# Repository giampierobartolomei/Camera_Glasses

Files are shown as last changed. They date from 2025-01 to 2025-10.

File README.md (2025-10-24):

# Camera_Glasses • Wearable camera system for synchronized multimodal data collection and research applications (adaption from ESP32-CAM_MJPEG2SD repo)

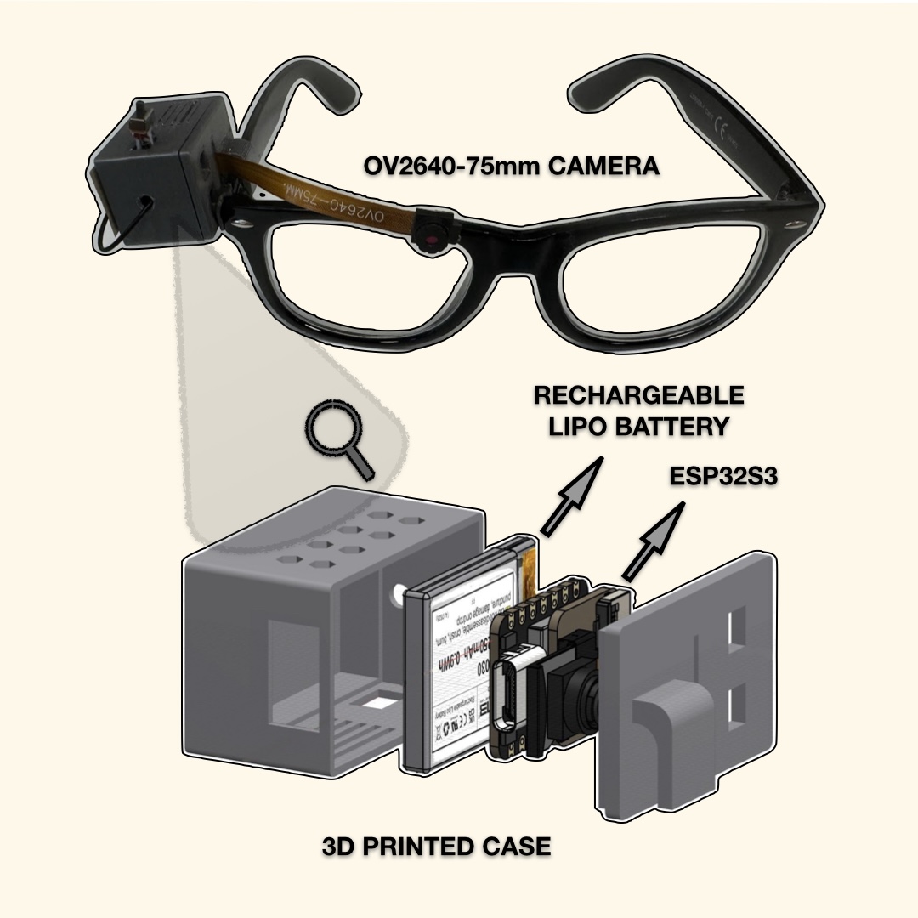
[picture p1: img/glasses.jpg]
Camera Glasses Overview


---

## Overview
The **Camera_Glasses** project provides a compact, wearable vision system based on the ESP32 microcontroller for synchronized multimodal data acquisition.  
The device records and streams video, interfaces via **Bluetooth** with the **ECHO** and **IM‑TWIN** Android applications, and integrates seamlessly with the **Platform Application** for synchronized analysis.

---

## Bill of Materials
| Component | Description | Link |
|---|---|---|
| LP502030 3.7 V 250 mAh Li‑ion Polymer Battery | Rechargeable | [Amazon](https://amzn.eu/d/fRJ3vzB) |
| 3D Printed Case | STL provided in repo | GitHub |
| OV2640 2 MP 20 cm Camera Module (66° FOV) | Main sensor | [AliExpress](https://www.aliexpress.com) |
| Xiao ESP32 Module | Main controller | [AliExpress](https://www.aliexpress.com) |
| Misc. | Wires, switch, solder, 3M bioadhesive tape, super glue | — |

---

## Hardware Assembly

### Components Overview
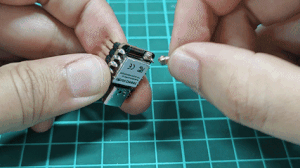
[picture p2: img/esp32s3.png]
Assembly Diagram


Follow the steps to assemble the prototype:

1. **3D print** the case (STL files provided in the repository).  
2. **Install** the antenna, expansion board, and 200 mm OV2640 camera.  
3. **Insert** a FAT32‑formatted microSD card.  
4. **Connect** the battery, switch, and camera module as shown below.  
5. **Assemble** and close the case, ensuring that the camera cable passes through the slot without bending.

### Battery and Switch Preparation
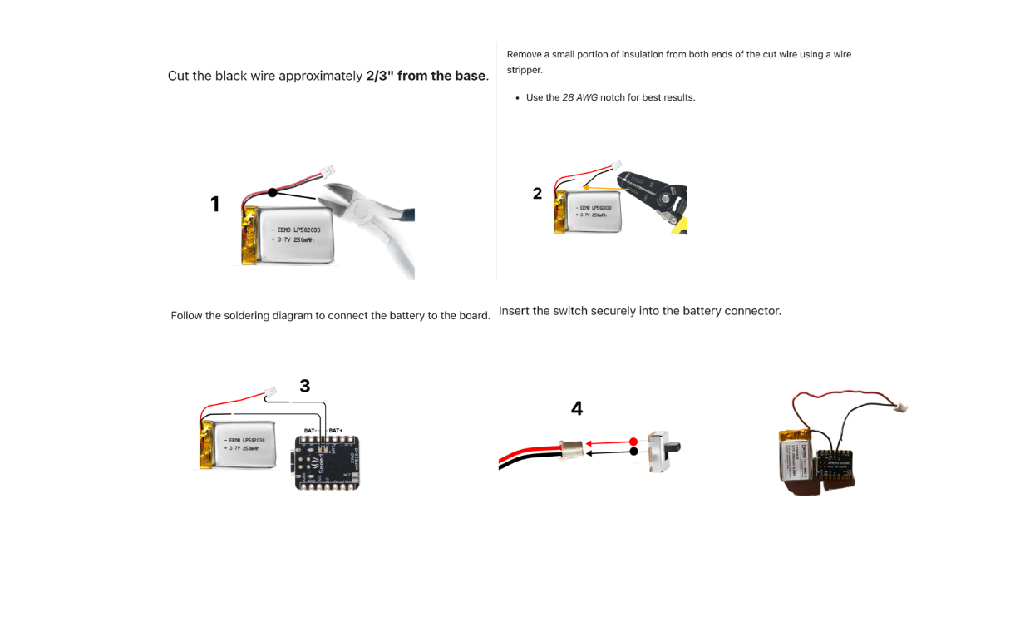
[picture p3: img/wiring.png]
Battery Wiring Steps


Ensure proper soldering of the switch and battery following the indicated diagram.

---

## Firmware Installation

1. Clone the repository:  
   ```bash
   git clone https://github.com/giampierobartolomei/Camera_Glasses.git
   ```
2. Copy the `data` folder (`CameraGlass/ESP32‑CAM_MJPEG2SD/data`) to the microSD card.  
3. Open the `.ino` file in Arduino IDE and check these settings:  
   - **Espressif Core:** 3.1.1  
   - **PSRAM:** Enabled (`Tools > PSRAM > OPI_PSRAM`)  
   - **Partition Scheme:** 3 MB APP  
4. If the upload fails, press and hold the **Boot** button while connecting the USB cable, then release it once uploading starts.

---

## First Use

The device now operates **via Bluetooth** only (Wi‑Fi mode deprecated).  
Default settings are pre‑loaded: **SVGA (800×600), 20 fps, motion detect disabled**.

### Recording Control Options

#### 1. Using Smartphone (nRF Connect)
- Connect to **CameraModule** via Bluetooth.  
- Send the UTF‑8 string commands:  
  - `rec` → start recording  
  - `stp` → stop recording  

#### 2. Using ECHO or IM‑TWIN Android App
- Connect the **TWC device** and tap the **Camera** button.  
- Once connected, the button turns **green**.  
- Tap **Rec** to start/stop recording.  
- The orange LED on the glasses blinks during active recording.

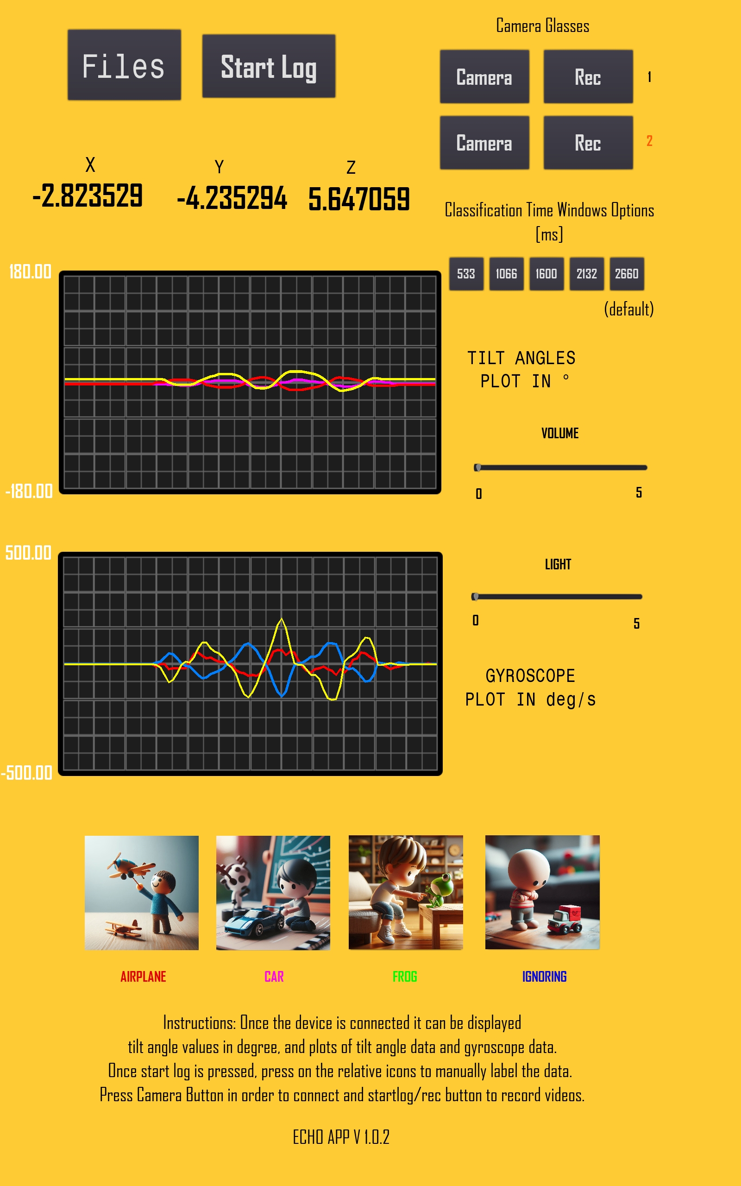
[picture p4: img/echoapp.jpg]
ECHO App Interface


---

## Computer Vision Integration

To process recorded videos with the **Computer Vision repository**:

1. Record video and save it to the microSD card.  
2. Copy `.avi` file to the computer and convert to `.mp4`:  
   ```bash
   ffmpeg -i input.avi -c:v libx264 -crf 23 -preset medium -c:a aac -b:a 128k output.mp4
   ```
3. If rotation is needed:  
   ```bash
   ffmpeg -i output.mp4 -vf "transpose=2" -c:a copy output_r.mp4
   ```

To synchronize with ECHO logs:
1. Save ECHO log as `.csv`.  
2. Process using `downsampling.py` and `plotanimation.py` (available in the **Echo repository**).  
3. Compare results using **Platform Application** for unified visualization.

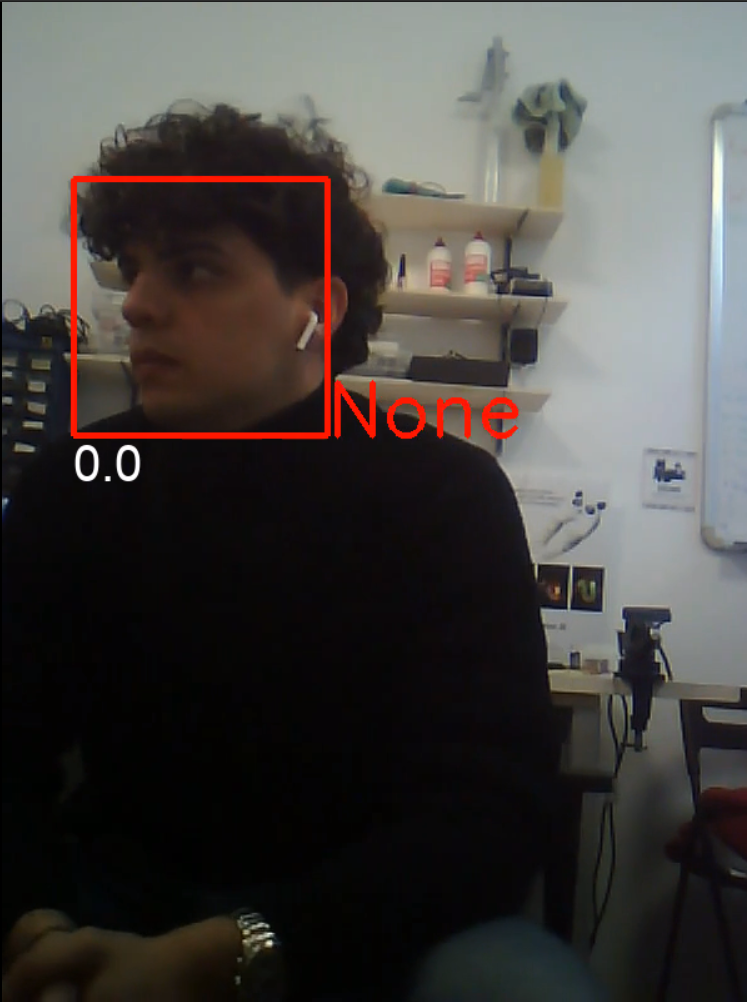
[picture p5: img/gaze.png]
Gaze Analysis Example


---

## Charging and Power Monitoring

- Connect a **USB‑C cable** while the device is ON.  
- The red LED inside the port blinks during charging and turns off when complete.  
- The orange LED indicates device power.  
- For battery voltage reading, use a 100 kΩ + 100 kΩ voltage divider (D4 → GND / Battery +).

---

## Platform Integration

1. Mount **Camera Glasses** and **ECHO**.  
2. Flash firmware and install the **ECHO App**.  
3. Turn on both devices (red LED for ECHO, orange LED for glasses).  
4. Connect via the app; both camera buttons should turn green when ready.  
5. Press **Start LOG** to begin synchronized recording.  
6. For new sessions, restart the app to ensure correct timestamps.  
7. Save logs and videos, convert with FFmpeg, and load into the **Platform Application** for analysis.

Platform GUI

---

## Repository Layout
```
Camera_Glasses/
├─ firmware/                # Arduino firmware (.ino)
├─ data/                    # Web UI / static assets
├─ 3d_models/               # STL case and lens holder
├─ docs/                    # images, diagrams
└─ README.md
```

---

## License
Code released under the **MIT License**.  
Images and documentation under **CC BY 4.0**.

---

## Citation
If you use Camera_Glasses in academic work, please cite this repository and the related Echo and Platform publications.

---

Exploded View

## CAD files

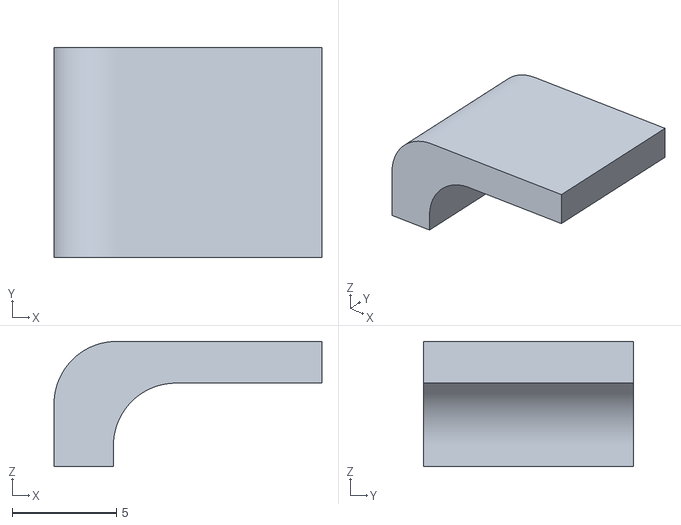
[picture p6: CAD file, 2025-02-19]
stl case files/gancio.stl
12.8 x 10.1 x 6.00

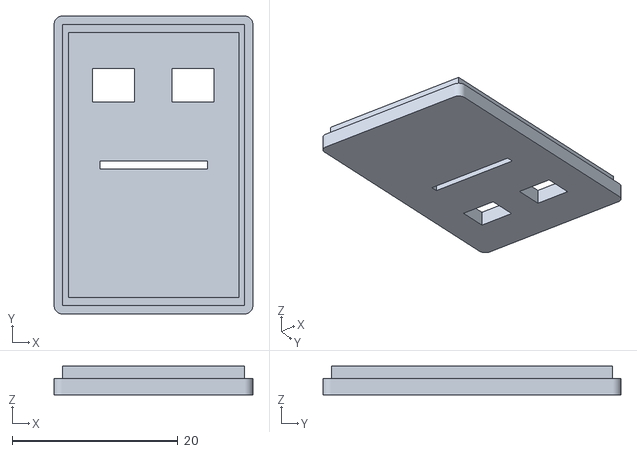
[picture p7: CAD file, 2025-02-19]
stl case files/tappo.stl
24.0 x 36.0 x 3.50

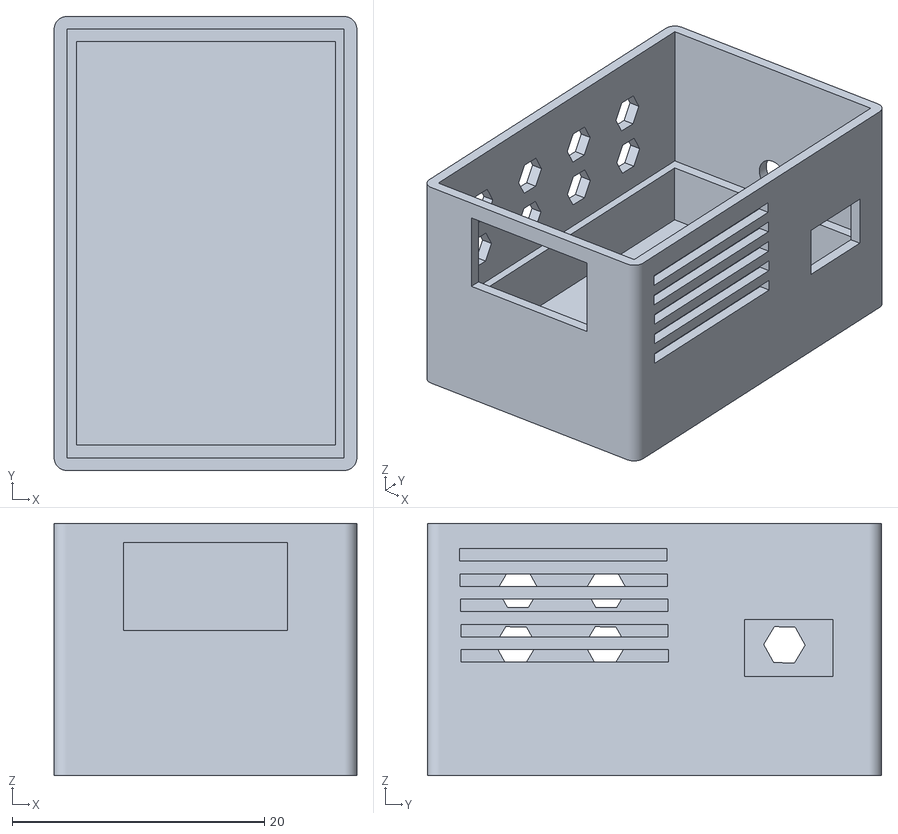
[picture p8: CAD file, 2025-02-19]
stl case files/base.stl
24.0 x 36.0 x 20.0

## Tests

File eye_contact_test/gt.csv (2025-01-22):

gt
0
0
0
0
0
0
0
0
0
0
0
0
0
0
0
0
0
0
0
0
0
0
0
1
1
1
1
1
1
1
1
1
1
1
1
1
1
1
1
0
0
0
0
0
1
1
1
1
1
1
1
1
1
1
0
0
0
0
0
0
0
1
1
1
1
1
1
1
1
1
1
1
0
0
0
0
0
0
0
0
0
0
0
0
1
1
1
1
1
1
1
1
1
1
0
1
1
1
1
1
1
1
1
1
1
1
1
1
1
1
1
1
1
1
1
1
1
1
1
1
1
1
1
1
0
0
0
0
0
0
1
1
1
1
1
1
1
1
1
1
1
1
1
1
1
1
1
1
1
1
1
1
1
1
1
1
1
1
0
0
0
0
0
0
0
0
0
0
0
0
0
0
0
0
0
0
0
0
0
0
0
0
0
0
0
0
0
0
1
1
1
1
1
1
1
1
1
0
0
0
0
0
0
0
0
0
0
0
0
0
0
0
0
0
0
0
0
0
0
0
0
0
0
0
0
0
0
0
1
1
1
1
1
1
1
1
1
1
1
1
1
1
1
1
1
1
1
1
1
1
1
1
1
1
1
1
1
1
1
1
1
1
1
1
1
1
1
1
1
1
1
1
1
1
1
1
0
0
0
0
1
1
1
1
1
1
1
1
1
1
1
1
1
1
1
1
1
1
1
1
1
1
1
0
0
0
0
0
1
1
1
1
1
1
1
1
1
1
1
1
1
1
1
1
0
0
0
0
0
0
0
0
0
0
0
0
0
0
0
1
1
1
1
1
1
1
1
0
1
1
1
1
1
1
1
1
1
1
1
1
1
1
1
1
1
1
1
1
0
0
0
1
1
1
1
1
0
0
0
0
0
0
0
0
0
0
0
0
0
0
0
0
0
0
0
0
0
0
0
0
0
0
0
0
0
0
0
0
0
0
0
0
0
0
0
0
0
0
0
0
0
0
0
0
0
0
0
0
0
0
0
0
0
0
0
0
0
0
0
0
0
0
0
0
0
0
0
0
0
0
0
0
0
0
0
0
0
0
0
0
0
0
0
0
0
0
0
0
0
0
0
0
0
0
0
0
0
0
0
0
0
0
0
1
1
1
1
1
1
1
1
1
1
1
0
0
0
0
0
0
0
0
0
0
0
0
0
0
0
0
0
0
0
0
0
0
0
0
0
0
0
0
0
0
0
0
0
0
0
0
0
0
0
0
0
0
0
0
0
0
0
0
0
0
0
0
0
0
0
0
0
0
0
0
0
0
0
0
0
0
0
0
0
0
0
0
0
0
0
0
0
0
0
0
0
0
0
0
0
0
0
0
0
0
0
0
0
0
0
0
0
0
0
0
0
0
0
0
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

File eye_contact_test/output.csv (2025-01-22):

output
0
0
0
0
0
0
0
0
0
0
0
0
0
0
0
0
0
0
0
0
0
0
0
0
0
0
0
0
0
0
0
0
0
0
0
0
0
0
0
0
0
0
0
1
1
1
1
1
0
0
1
1
1
1
0
0
0
0
0
0
0
0
1
1
1
1
1
1
1
1
1
1
0
0
1
0
0
0
0
0
1
0
0
0
1
1
1
1
1
1
1
1
1
1
0
0
1
1
1
1
1
1
1
1
1
1
1
1
1
1
1
1
1
1
1
1
1
1
1
1
1
1
1
1
0
0
0
0
1
1
1
1
1
1
1
1
1
1
1
1
1
1
1
1
1
1
1
1
1
1
1
1
1
1
1
1
1
1
0
0
1
0
0
0
0
0
0
0
0
0
0
0
0
0
0
0
0
0
0
0
0
1
0
0
0
0
0
0
1
1
1
1
1
1
1
1
0
0
0
0
0
0
0
0
0
0
0
0
0
0
0
0
0
0
0
0
0
0
0
0
0
0
0
0
0
0
0
0
1
1
1
1
1
1
1
1
1
1
1
1
1
1
1
1
1
1
1
1
1
1
1
1
1
1
1
1
1
1
1
1
1
1
1
1
1
1
1
1
1
1
1
1
1
1
1
1
0
0
0
0
1
1
1
1
1
1
1
1
1
1
1
1
1
1
1
1
1
1
1
1
1
1
1
1
0
0
0
1
1
1
1
1
1
1
1
1
1
1
1
1
1
1
1
1
1
1
0
0
0
0
0
0
0
0
0
0
0
0
1
1
1
1
1
1
1
1
1
0
0
1
1
1
1
1
1
1
1
1
1
1
1
1
1
1
1
1
1
1
0
0
0
1
1
1
1
0
0
0
0
0
0
0
0
0
0
0
0
0
0
0
0
0
0
0
0
0
0
0
0
0
0
0
0
0
0
0
0
0
0
0
0
0
0
1
0
0
0
0
0
1
0
1
1
0
0
1
1
1
1
1
1
1
0
0
1
0
0
0
1
0
0
0
0
0
0
0
0
0
0
0
0
0
0
0
0
0
0
0
0
0
0
0
0
0
0
0
0
0
0
0
0
0
0
0
0
0
0
0
0
0
0
0
0
1
1
1
1
1
1
1
1
1
1
1
0
0
0
0
0
0
0
0
0
0
0
0
0
0
0
0
0
0
0
0
0
0
0
0
0
0
0
1
0
0
0
0
0
0
0
0
0
0
0
0
0
0
0
0
0
0
0
0
0
0
0
0
0
1
0
1
0
0
0
0
0
0
0
0
0
1
0
0
0
0
0
0
0
0
1
0
0
0
0
0
0
0
0
0
0
0
0
0
0
0
0
0
0
0
0
0
0
0
0
0
0
0
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

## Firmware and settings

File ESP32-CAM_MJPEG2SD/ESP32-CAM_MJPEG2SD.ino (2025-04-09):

/*
* Capture ESP32 Cam JPEG images into a AVI file and store on SD
* AVI files stored on the SD card can also be selected and streamed to a browser as MJPEG.
*
* s60sc 2020 - 2024

8/02: I tried to add prints on serial for battery voltage status, by modifyng this code, appGlobals.h, globals.h, pheriperals.cpp
Then I try to add WebDav functionalities. I modified also utils.cpp by putting to false use ping and setting ap ip and name.
12/02: I defined as const useMotion and commented all others declarations - it works, no more autorecording
17/02: Now battery voltage is sent on command char every ten seconds (uncomment the serial prints to read in serial monitor) in file BluetoothCamerServer.cpp. try using nRF connect iPhone app (UTF-8)
18/02: i changed max_adc values since it can change with device changing, you can see the comment in bt lib .cpp. i added also a factor for correcting R tollerance.I also modified mjpeg2sd in order to blink orange LED during recording as a DEBUG of the recording status.
24/02: ADDED AUDIO RECORDING!!!! modified appglobals appspecific & audio.cpp in order to force audio recording (by surpassing app settings) video file will contain '_S' on the end of filename. micGain is now 5 but can be higher. 
*/

#include "appGlobals.h"
//#include "SerialCommandHandler.h" //added by me
#include "BluetoothCameraServer.h" //Added by me, from max code

bool forceRecord = false; // added by me and commented the declaratiion in mjpeg2sd.cpp
//bool useMotion  == false; // whether to use camera for motion detection (with motionDetect.cpp), added by me, but only with changs on motionDetect.cpp it works
const bool useMotion = false; // Variabile costante, non modificabile

void setup() {
  logSetup();
  LOG_INF("Selected board %s", CAM_BOARD);
  // Legge e stampa subito la tensione della batteria
  float voltage = readVoltage();
  LOG_INF("Initial battery voltage: %.2fV", voltage);
  // prep storage
  if (startStorage()) {
    // Load saved user configuration
    if (loadConfig()) {
#ifndef AUXILIARY
      // initialise camera
      if (psramFound()) {
        if (ESP.getPsramSize() > 3 * ONEMEG) prepCam();
        else snprintf(startupFailure, SF_LEN, STARTUP_FAIL "Insufficient PSRAM for app: %s", fmtSize(ESP.getPsramSize()));
      } else snprintf(startupFailure, SF_LEN, STARTUP_FAIL "Need PSRAM to be enabled");
#else
      LOG_INF("AUXILIARY mode without camera");
#endif
    }
  }
  
#ifdef DEV_ONLY
  devSetup();
#endif

  // connect wifi or start config AP if router details not available
//  startWifi();

//  startWebServer();
  if (strlen(startupFailure)) LOG_WRN("%s", startupFailure);
  else {
    // start rest of services
#ifndef AUXILIARY
    startSustainTasks(); 
#endif
#if INCLUDE_SMTP
    prepSMTP(); 
#endif
#if INCLUDE_FTP_HFS
    prepUpload();
#endif
#if INCLUDE_UART
    prepUart();
#endif
#if INCLUDE_PERIPH
    prepPeripherals();
  #if INCLUDE_MCPWM 
    prepMotors();
  #endif
#endif
#if INCLUDE_AUDIO
    prepAudio(); 
#endif
#if INCLUDE_TGRAM
    prepTelegram();
#endif
#ifndef AUXILIARY
    prepRecording(); 
#endif
#if INCLUDE_I2C
  prepI2C();
  #if INCLUDE_TELEM
    prepTelemetry();
  #endif
#endif
#if INCLUDE_PERIPH
    startHeartbeat();
#endif
#if INCLUDE_RTSP
    prepRTSP();
#endif
    checkMemory("Setup");
    if (DEBUG_MEM) runTaskStats();
  } 
  
  setup_BLE_ESP32(); //from max code
  //startSerialCommandTask(forceRecord); //added by me for serial input start/stop recording and video saving
}
//It should appear: first battery level voltage(commented), pheripherals setup, total tasks and then the updating of the battery level every interval setted in bt library file .cpp (commented)
void loop() {
  // confirm not blocked in setup
  //float voltage = (float)(smoothAnalog(5)) * 3.3 * 2 / 8191;
  //LOG_INF("Initial battery voltage: %.2fV", voltage);
  LOG_INF("=============== Total tasks: %u ===============\n", uxTaskGetNumberOfTasks() - 1);
  vTaskDelete(NULL); // free 8k ram
}

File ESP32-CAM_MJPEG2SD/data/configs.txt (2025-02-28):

AP_Pass~~0~T~AP Password
AP_SSID~ESP-CAM_MJPEG_C025130CDADC~0~T~AP SSID name
AP_gw~~0~T~AP gateway
AP_ip~~0~T~AP IP Address if not 192.168.4.1
AP_sn~~0~T~AP subnet
AtakePhotos~Start~5~A~Start photogrammetry
AudActive~0~3~C~Show audio configuration
Auth_Name~~99~~na
AuxIP~~3~T~Send RC / Servo / PG commands to auxiliary IP
BabortPhotos~Abort~5~A~Abort photogrammetry
I2Cscl~-1~3~N~I2C SCL pin if unshared
I2Csda~-1~3~N~I2C SDA pin if unshared
PGactive~0~3~C~Enable photogrammetry
RCactive~0~3~C~Enable remote control
RPM~1~5~N~Turntable revolution speed as RPM
ST_SSID~0~99~~na
ST_gw~~0~T~Router IP address
ST_ip~~0~T~Static IP address
ST_ns1~~0~T~DNS server
ST_ns2~~0~T~Alt DNS server
ST_sn~255.255.255.0~0~T~Router subnet
SVactive~0~3~C~Enable servo use
ae_level~-2~98~~na
aec~1~98~~na
aec2~1~98~~na
aec_value~204~98~~na
agc~1~98~~na
agc_gain~0~98~~na
alarmHour~1~2~N~Hour of day for daily actions
allowAP~1~0~C~Allow simultaneous AP 
allowReverse~1~4~C~Reverse motion required
ampVol~0~98~~na
appId~ESP-CAM_MJPEG~99~~na
autoControl~1~4~C~Stop motor or center steering if control inactive
autoUpload~0~98~~na
awb~1~98~~na
awb_gain~1~98~~na
bpc~1~98~~na
brightness~0~98~~na
buzzerDuration~~3~N~Duration of buzzer sound in secs
buzzerPin~~3~N~Pin used for active buzzer
buzzerUse~0~3~C~Use active buzzer
cfgVer~25~99~T~na
clockwise~1~5~C~Clockwise turntable if true
colorbar~0~98~~na
contrast~0~98~~na
dcw~1~98~~na
deleteAfter~0~98~~na
denoise~4~98~~na
depthColor~0~1~C~Color depth for motion detection: Gray <> RGB
detectChangeThreshold~15~1~N~Pixel difference to indicate change
detectEndBand~8~1~N~Bottom band where motion is checked
detectMotionFrames~5~1~N~Num changed frames to start motion
detectNightFrames~10~1~N~Min dark frames to indicate night
detectNumBands~10~1~N~Total num of detection bands
detectStartBand~3~1~N~Top band where motion is checked
devHub~0~2~C~Show Camera Hub tab
doGetExtIP~1~0~C~Enable get external IP
ds18b20Pin~~3~N~Pin used for DS18B20 temperature sensor
enableMotion~0~98~~na
extCam~0~5~C~Use external camera
extIP~~99~~na
external_heartbeat_active~0~2~C~External Heartbeat Server enabled
external_heartbeat_domain~~2~T~Heartbeat receiver domain or IP (eg. www.espsee.com)
external_heartbeat_port~443~2~N~Heartbeat receiver port
external_heartbeat_token~~2~T~Heartbeat receiver auth token
external_heartbeat_uri~~2~T~Heartbeat receiver URI (eg. /heartbeat/)
formatIfMountFailed~0~2~C~Format file system on failure
fps~20~98~~na
framesize~11~98~~na
fsPort~21~99~~na
fsServer~~99~~na
fsUse~~99~~na
fsWd~~99~~na
ftpUser~~99~~na
gainceiling~0~98~~na
gearing~5.7~5~N~Turntable / motor gearing ratio
heartbeatRC~5~4~N~RC connection heartbeat time (secs)
hmirror~0~98~~na
hostName~ESP-CAM_MJPEG_C025130CDADC~99~T~Device host name
lampLevel~0~98~~na
lampPin~21~3~N~Pin used for Lamp
lampType~0~3~S:Manual:PIR~How lamp activated
lenc~1~98~~na
lightsRCpin~~4~N~Pin used for RC lights output
logType~0~99~N~Output log selection
lswitch~10~98~~na
mampBckIo~-1~7~N~Amplifier I2S BCLK (SCK) pin
mampSdIo~-1~7~N~Amplifier I2S DIN pin
mampSwsIo~-1~7~N~Amplifier I2S LRCLK (WS) pin
maxDutyCycle~100~4~N~Max motor duty cycle % (speed)
maxFrames~20000~1~N~Max frames in recording
maxSteerAngle~45~4~N~Max steering angle from straightahead
maxTurnSpeed~50~4~N~Max tracked turn speed differential 
micGain~10~98~~na
micSWsPin~42~7~N~Microphone I2S WS, PDM CLK pin
micSckPin~-1~7~N~Microphone I2S SCK pin
micSdPin~41~7~N~Microphone I2S SD, PDM DAT pin
minDutyCycle~10~4~N~Min motor duty cycle % (stop)
minf~5~98~~na
mlProbability~0.8~1~N~ML minimum positive probability 0.0 - 1.0
mlUse~0~1~C~Use Machine Learning
motionVal~8~98~~na
motorFwdPin~~4~N~Pin used for motor forward / left track 
motorFwdPinR~~4~N~Pin used for right track forward
motorRevPin~~4~N~Pin used for motor reverse / left track 
motorRevPinR~~4~N~Pin used for right track reverse
moveStartChecks~5~1~N~Checks per second for start motion
moveStopSecs~2~1~N~Non movement to stop recording (secs)
mqtt_active~0~2~C~Mqtt enabled
mqtt_broker~~2~T~Mqtt server ip to connect
mqtt_port~1883~2~N~Mqtt server port
mqtt_topic_prefix~homeassistant/~2~T~Mqtt topic path prefix
mqtt_user~~2~T~Mqtt user name
mqtt_user_Pass~~2~T~Mqtt user password
ntpServer~pool.ntp.org~0~T~NTP Server address
numberOfPhotos~20~5~N~Number of photos
pinFocus~-1~5~N~Pin connected to camera focus
pinShutter~-1~5~N~Pin connected to camera shutter
pirPin~~3~N~Pin used for PIR
pirUse~0~3~C~Use PIR for detection
pwmFreq~50~4~N~RC Motor PWM frequency
quality~4~98~~na
raw_gma~1~98~~na
record~0~98~~na
refreshVal~5~2~N~Web page refresh rate (secs)
relayMode~0~3~S:Manual:Night~How relay activated
relayPin~-1~3~N~Pin to switch relay 
relaySwitch~0~3~C~Switch relay off / on
responseTimeoutSecs~10~2~N~Server response timeout (secs)
restart~~99~~na
rtsp0Video~1~8~C~Enable RTSP Video
rtsp1Audio~0~8~C~Enable RTSP Audio
rtsp2Subtitles~1~8~C~Enable RTSP Subtitles
rtsp3Port~554~8~N~RTSP ServerPort
rtsp4VideoPort~5430~8~N~RTSP Video Port
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

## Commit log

2025-01-15 initial commit, now the code allows to record video from serial input.
    [openglass_case.stl, partitions.csv]
2025-01-22 tried to add audio/battery state but not functioning, added test and R script for kappa value
    [gt.csv, output.csv]
2025-02-07 added: battery status(not working), disabled by default motion detect & added USER GUIDE (to be updated)
    [ESP32-CAM_MJPEG2SD.ino, mjpeg2sd.cpp, peripherals.cpp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]
2025-02-08 added prints for battery level(to test) and webdav functionalities. It rest only to control how to use Wifi functionalities in a stable way
2025-02-18 corrected battery level bt communication and added led blinking while recording
    [BluetoothCameraServer.cpp, ESP32-CAM_MJPEG2SD.ino, appGlobals.h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]
2025-02-19 CAMERAGLASS 1.0 - record your video and save it on SD by BT commands (orange led will blink during recording), read the battery voltage. new case printed.
    [base.stl, gancio.stl, openglass_case.stl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]
2025-02-24 ADDED AUDIO RECORDING AND DELETED OLD CASE FILE
2025-02-28 1.0.1: ADDED CONFIG FILE & CHANGES TO WIFI TO WORK ONLY IN AP MODE (ATTENTION UNSTABLE)
    [configs.txt]
2025-04-09 aggiunti comandi al readme per ruotare video quando camera montata girata
2025-04-22 added 2nd camera instructions & platform v1.0
